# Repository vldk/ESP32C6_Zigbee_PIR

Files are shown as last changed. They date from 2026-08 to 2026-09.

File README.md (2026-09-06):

# ESP32-C6 Zigbee PIR presence sensor (ESP-IDF)

Native ESP-IDF port of `docs/esp32c6_AM312_pullup_v3_2.ino`, with the deep-sleep
cycle replaced by the esp-zigbee sleep feature (automatic light sleep).

- Board: Seeed XIAO ESP32-C6
- Stack: ESP-IDF 6.0.1 + `espressif/esp-zigbee-lib` 1.6.x (Zigbee End Device)
- Build: PlatformIO, `framework = espidf`

---

## Why the sleep mode changed

The Arduino sketch did all its work inside `setup()` and ended every wake in
`esp_deep_sleep_start()`. Deep sleep wipes RAM, so each motion event paid for a
full boot, radio init and parent rejoin before the occupancy report could leave
the device.

Light sleep keeps RAM, the radio state and the network join intact. The Zigbee
stack raises `ESP_ZB_COMMON_SIGNAL_CAN_SLEEP` whenever it is idle;
`esp_zb_sleep_now()` releases its power-management lock, and the IDF tickless
idle takes the SoC down until the next parent poll, GPIO edge or timer alarm.

| | Deep sleep (sketch) | Light sleep (this port) |
|---|---|---|
| Motion report latency | boot + rejoin | milliseconds |
| RAM across sleep | lost | retained |
| Motion vs. button wake | ambiguous, disambiguated by re-reading GPIO7 | distinct interrupts |
| z2m config write | needed an explicit `CONFIG_LISTEN_S` awake window | arrives on the next ordinary parent poll |
| Occupancy hold | busy-wait loop with `delay(50)` | `esp_timer`, asleep in between |

---

## Runtime shape

Every module is a producer; `app_task` in `main.c` is the only consumer, so all
application state lives on one thread and needs no locking.

```
   GPIO1 (PIR) ──┐  level ISR
   GPIO7 (btn) ──┤  + light-sleep wake
                 │
        board_io ├──────────────┐
                 │              │
   esp_timer ────┤ hold         ├──►  s_events queue  ──►  app_task
   alarms        │ supervise    │                            │
                 │ heartbeat    │                            │
                 │ reset-hold   │                            │
                 │              │                            ▼
        zb_sensor├──────────────┘                    set_occupancy()
        (stack task)                                 report_battery()
             ▲                                       settings_set_hold_s()
             └───────────────────────────────────────────────┘
                        esp_zb_lock_acquire()
```

| File | Responsibility |
|---|---|
| `src/app_config.h` | every pin and tunable, single source of truth |
| `src/app_events.h` | the one message type crossing thread boundaries |
| `src/board_io.c` | PIR / button / LED, GPIO light-sleep wake |
| `src/battery.c` | ADC oneshot + curve-fitting calibration -> mV, % |
| `src/settings.c` | NVS store for the occupancy hold setpoint |
| `src/zb_sensor.c` | endpoints, clusters, reports, signal handler, sleep hook |
| `src/main.c` | wiring and the occupancy state machine |

---

## The one subtle part: level-triggered GPIO

The GPIO peripheral is clocked from APB, which stops during light sleep, so an
**edge** that happens while the chip sleeps is lost. Only a **level** survives:
`gpio_wakeup_enable()` wakes the chip while the pin sits at the configured
level, and that level is still there when the ISR finally runs.

So `board_io.c` arms each input for the level it does *not* currently have —
for both the wake source and the interrupt — and flips the watch after every
transition:

```
idle (HIGH) ──arm LOW──►  motion asserted (LOW) ──arm HIGH──►  released ──►  idle
```

The ISR masks the pin (a level interrupt would re-enter forever) and the
application calls `board_io_rearm()` once it has acted. If the line flips back
between the two, the newly armed level already matches and the interrupt fires
immediately — one spurious wake, then self-corrected, never a lost edge.

Two related sdkconfig points:

- `CONFIG_PM_POWER_DOWN_PERIPHERAL_IN_LIGHT_SLEEP=n` — powering the HP
  peripherals down takes the GPIO block with them and makes
  `esp_sleep_enable_gpio_wakeup()` unavailable.
- `CONFIG_PM_SLP_DISABLE_GPIO` is on by default and parks every pad during
  sleep; `gpio_sleep_sel_dis()` is the documented opt-out, applied to the PIR,
  the button and the LED.

---

## The other subtle part: occupancy lives in two places

Keeping RAM across sleep bought fast reports, but it also introduced a problem
deep sleep did not have. The sketch rebooted on every wake and re-reported
occupancy unconditionally each time — including on no-motion heartbeat wakes —
so the coordinator was re-synchronised roughly hourly for free. This port holds
the state in RAM and `set_occupancy()` deduplicates, so a single report that
fails to leave the device desynchronises the coordinator **permanently**: the
device never repeats itself, and z2m has nothing to correct it with.

That is not hypothetical. On 2026-09-04 the sensor reported occupied at
07:20:13Z and z2m did not see a clear until 08:07:53Z — 47 minutes, against a
hold of a few seconds and a 180 s ceiling — while staying joined, reachable and
delivering its heartbeat throughout. Only the next physical motion repaired it,
because `extend_hold()` runs on every PIR edge regardless of the dedupe.

Three mechanisms now reconcile the two copies:

| when | what | covers |
|---|---|---|
| on every report | `publish_occupancy()` records failure in `s_occupancy_unreported` | a report that never left the radio |
| every `OCCUPANCY_SUPERVISE_S` | retry an unreported state; force-clear occupancy older than `OCCUPANCY_MAX_HOLD_S` | a hold timer that never fired |
| every `HEARTBEAT_S` | unconditional re-publish, bypassing the dedupe | everything else |

The force-clear deliberately does **not** live in the hold-timer callback.
`handle_hold_expired()` enforces the same 180 s ceiling, but only when the hold
timer fires — which is exactly the assumption that fails when the state is
stuck. A guard inside the mechanism it guards is not a safety net.

`zb_sensor.c` supports this by returning `ESP_ERR_INVALID_STATE` rather than
`ESP_OK` when a report is skipped because the device is not joined. Reporting
success for something that was never transmitted is what made the failure
invisible in the first place.

---

## Zigbee model

Unchanged from the sketch, so an existing zigbee2mqtt converter keeps working.
All reports are sent **unsolicited**: a sleepy end device never completes the
bind + configureReporting handshake z2m normally does, because it times out
while the device is asleep.

| EP | Cluster | Purpose |
|---|---|---|
| 10 | Occupancy Sensing | `occupancy` |
| 10 | Power Config | `batteryPercentageRemaining` (half-percent units) |
| 11 | Analog Input | battery volts — reportable, unlike the read-only Power-Config `BatteryVoltage` |
| 12 | Analog Output | occupancy hold setpoint in seconds, writable from z2m |

A write to `genAnalogOutput.presentValue` on EP 12 is clamped to
`OCCUPANCY_HOLD_MIN_S..OCCUPANCY_HOLD_MAX_S`, persisted to NVS only when it
actually changed, and echoed back so z2m displays the accepted value. It also
applies to an occupancy period already in progress.

The z2m external converter is `docs/esp32c6_AM312_pullup.mjs`. It accepts both
`AM312_Presence_v2` (the Arduino sketch) and `AM312_Presence_v3` (this port),
since the Zigbee model is identical between them - only the model identifier
string changed.

---

## Hardware

```
  AM312 OUT --[100k]--> Base (2N3904 / BC547 / BC337)
                        Emitter --> GND
                        Collector --> D1 / GPIO1
  D1 / GPIO1 --[1M]--> 3V3          (idle pull-up)

  No motion : AM312 OUT = 0V   -> NPN off -> D1 = HIGH
  Motion    : AM312 OUT = 1.8V -> NPN on  -> D1 = LOW
```

- Battery: LiPo on the BAT pads, `2x1M` divider midpoint -> D0 / GPIO0.
- Factory reset: external momentary switch from GPIO7 (D7) to GND, held 5 s.
  GPIO7 has no on-board button — the physical BOOT button is the GPIO9 strap
  pin and is unusable here.

---

## Build and flash

```bash
pio run                  # build
pio run -t upload        # flash
pio device monitor       # logs (115200, USB-Serial-JTAG)
pio run -t menuconfig    # stack / PM options
```

`sdkconfig.defaults` is only consulted when the per-environment `sdkconfig` is
generated. After editing it, delete `sdkconfig.seeed_xiao_esp32c6` and rebuild.

`board_build.partitions` in `platformio.ini` has to name the same file as
`CONFIG_PARTITION_TABLE_CUSTOM_FILENAME`: PlatformIO generates the partition
table itself and ignores the sdkconfig value. Without it the build silently
falls back to the single-app table and the stack loses `zb_storage`/`zb_fct`.

### Logging

The runtime log level is `CONFIG_LOG_DEFAULT_LEVEL_NONE`, so the firmware is
silent by default: logging over USB-Serial-JTAG keeps that peripheral alive and
dominates the sleep current, and every log call also lengthens the wake it
happens in.

`CONFIG_LOG_MAXIMUM_LEVEL_INFO` is kept, so the strings stay linked (~200 B of
flash) and `esp_log_level_set()` can raise the level at runtime. Note there is
no console or shell on this device to call it from — in practice, getting logs
back means rebuilding with `CONFIG_LOG_DEFAULT_LEVEL_INFO=y`, deleting
`sdkconfig.seeed_xiao_esp32c6` and reflashing. Set
`CONFIG_LOG_MAXIMUM_LEVEL_NONE=y` as well if you want the strings gone
entirely and will never re-enable them.

The two lines worth watching when diagnosing an occupancy desync are
`occupancy -> clear` and `re-sending unreported occupancy state`.

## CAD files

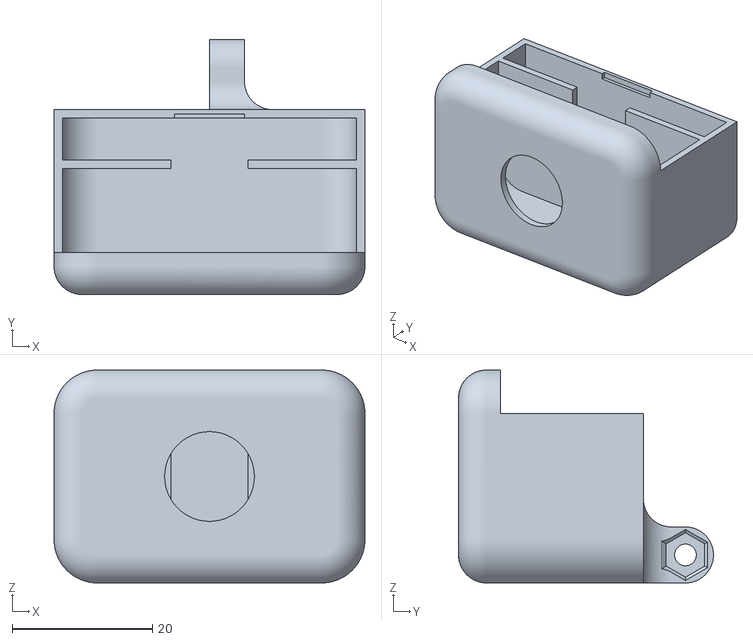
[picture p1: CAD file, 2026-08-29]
3dprint/ESP32C6_PIR_sensor - MainCover.stl
44.4 x 36.4 x 30.4

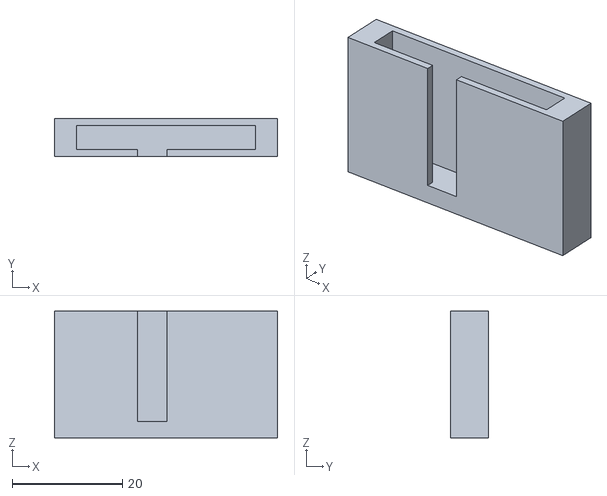
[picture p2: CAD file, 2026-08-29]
3dprint/ESP32C6_PIR_sensor - wallMount.stl
40.4 x 6.80 x 23.0

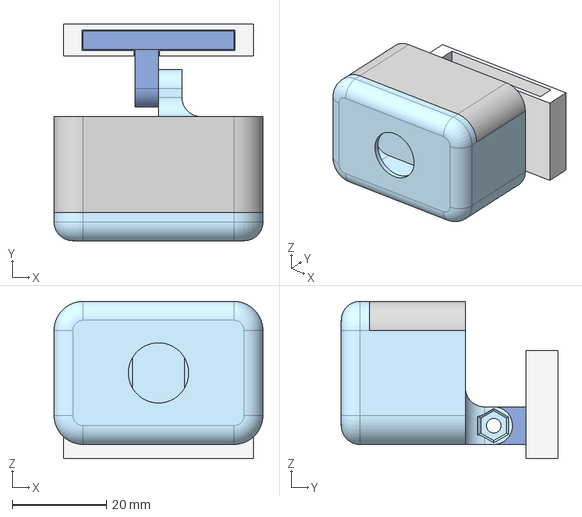
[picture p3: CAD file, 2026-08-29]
3dprint/ESP32C6_PIR_sensor.step
44.4 x 46.0 x 33.4 mm

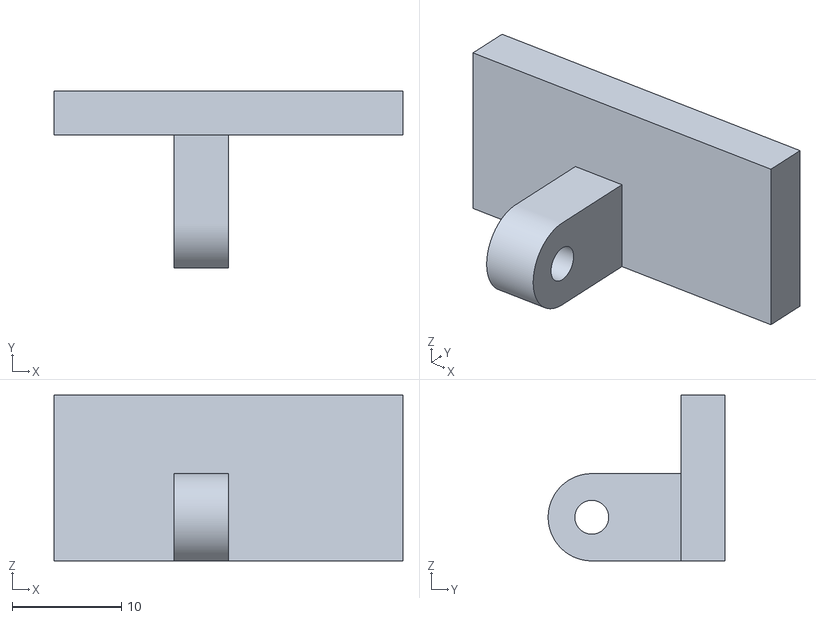
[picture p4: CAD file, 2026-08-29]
3dprint/ESP32C6_PIR_sensor - mountAdapter.stl
32.0 x 16.2 x 15.2

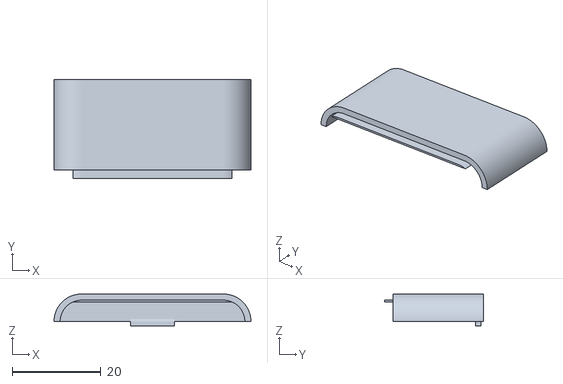
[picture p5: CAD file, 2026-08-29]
3dprint/ESP32C6_PIR_sensor - TopLid.stl
44.4 x 22.4 x 7.20

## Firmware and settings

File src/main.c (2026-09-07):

/*
 * Zigbee battery PIR presence sensor - ESP-IDF port of
 * docs/esp32c6_AM312_pullup_v3_2.ino
 * ---------------------------------------------------------------------------
 * Board : Seeed XIAO ESP32-C6
 * Sensor: AM312 mini PIR -> NPN buffer -> D1/GPIO1
 * Power : LiPo on the BAT pads, sensed through a 2x1M divider on D0/GPIO0
 *
 * What changed against the Arduino sketch
 * ---------------------------------------
 * The sketch ran its whole life inside setup() and ended every wake in
 * esp_deep_sleep_start(), so each motion event cost a full boot, radio init
 * and parent rejoin before the report could leave. This port keeps the device
 * running and joined, and lets the Zigbee stack drop into automatic light
 * sleep between events (see the CAN_SLEEP handler in zb_sensor.c). Practical
 * consequences:
 *
 *   - Motion is reported in milliseconds, not after a boot cycle.
 *   - No more "was this a motion wake or a button wake?" guessing: the GPIO
 *     that woke us also raises a normal interrupt, so the two are distinct.
 *   - The config-receive window is gone. A queued genAnalogOutput write from
 *     z2m is delivered on the next ordinary parent poll, so it no longer has
 *     to be waited for explicitly.
 *
 * Runtime shape - every module is a producer, this file is the only consumer:
 *
 *   board_io (GPIO ISR) --.
 *   esp_timer alarms -----+--> s_events queue --> app_task state machine
 *   zb_sensor (stack) ----'
 */

#include <inttypes.h>

#include "app_config.h"
#include "app_events.h"
#include "battery.h"
#include "board_io.h"
#include "esp_check.h"
#include "esp_log.h"
#include "esp_pm.h"
#include "esp_system.h"
#include "esp_timer.h"
#include "freertos/FreeRTOS.h"
#include "freertos/queue.h"
#include "freertos/task.h"
#include "nvs_flash.h"
#include "sdkconfig.h"
#include "settings.h"
#include "zb_sensor.h"

static const char *TAG = "app";

#define APP_QUEUE_LENGTH    12
#define APP_TASK_STACK_SIZE 4096
#define APP_TASK_PRIORITY   4

static QueueHandle_t     s_events;
static esp_timer_handle_t s_hold_timer;       /* occupancy stay-on          */
static esp_timer_handle_t s_supervise_timer;  /* occupancy state supervisor */
static esp_timer_handle_t s_heartbeat_timer;  /* periodic battery report    */
static esp_timer_handle_t s_reset_timer;      /* button held long enough    */

static bool    s_occupied;
static int64_t s_occupied_since_us;
/* When the hold is currently due to end. The queued APP_EVT_HOLD_EXPIRED is not
 * self-describing, so this is what tells a stale one from a real one - see
 * handle_hold_expired(). */
static int64_t s_hold_deadline_us;
/* Set when an occupancy report did not make it out. The coordinator is the only
 * place this state is visible to anyone, so a dropped report has to be retried
 * rather than logged and forgotten - see handle_supervise(). */
static bool    s_occupancy_unreported;
/* 0 while the device has a network. Otherwise when it lost one, which is what
 * lets handle_supervise() tell a rejoin that is in progress from one that is
 * never going to finish. Armed only after a first successful join, so pairing a
 * factory-new device is never interrupted by the reboot below. */
static int64_t s_link_down_since_us;

/* ------------------------------------------------------------------ timers */

/* esp_timer callbacks run in the timer task, so they only enqueue - all state
 * lives in app_task and needs no locking. */
static void timer_post_event(void *arg)
{
    const app_event_t evt = { .id = (app_event_id_t)(intptr_t)arg };
    if (xQueueSend(s_events, &evt, 0) != pdTRUE) {
        ESP_LOGW(TAG, "application queue full, dropped timer event %d", (int)evt.id);
    }
}

static esp_err_t timer_create(esp_timer_handle_t *out, app_event_id_t event_id, const char *name)
{
    const esp_timer_create_args_t args = {
        .callback = timer_post_event,
        .arg      = (void *)(intptr_t)event_id,
        .name     = name,
        /* ESP_TIMER_TASK, not ISR: the callback touches a FreeRTOS queue. */
        .dispatch_method = ESP_TIMER_TASK,
    };
    return esp_timer_create(&args, out);
}

static void timer_restart_once(esp_timer_handle_t timer, uint64_t timeout_us)
{
    /* esp_timer_stop() returns ESP_ERR_INVALID_STATE when the timer is not
     * armed, which is a normal case here, not an error. */
    esp_timer_stop(timer);

    const esp_err_t err = esp_timer_start_once(timer, timeout_us);
    if (err != ESP_OK) {
        ESP_LOGE(TAG, "cannot arm timer: %s", esp_err_to_name(err));
    }
}

/* -------------------------------------------------------------- occupancy */

/* The single point every occupancy report goes through, so that a failure is
 * remembered instead of merely logged. Local state is committed first on
 * purpose: the LED and the hold logic must reflect the sensor even when the
 * radio is unavailable. It is the coordinator that then has to catch up. */
static void publish_occupancy(void)
{
    const esp_err_t err = zb_sensor_report_occupancy(s_occupied);
    s_occupancy_unreported = (err != ESP_OK);

    if (err != ESP_OK) {
        ESP_LOGE(TAG, "occupancy report failed (%s), retrying within %u s",
                 esp_err_to_name(err), (unsigned)OCCUPANCY_SUPERVISE_S);
    }
}

static void set_occupancy(bool occupied)
{
    if (s_occupied == occupied) {
        /* Deduplicated, but never silently: if the last attempt for this very
         * value failed, the coordinator still disagrees with us and this is a
         * free chance to fix that. */
        if (s_occupancy_unreported) {
            publish_occupancy();
        }
        return;
    }
    s_occupied = occupied;
    if (occupied) {
        s_occupied_since_us = esp_timer_get_time();
    }

    ESP_LOGI(TAG, "occupancy -> %s", occupied ? "occupied" : "clear");

    publish_occupancy();
}

static void extend_hold(void)
{
    const uint64_t hold_us = (uint64_t)settings_get_hold_s() * 1000000ULL;

    s_hold_deadline_us = esp_timer_get_time() + (int64_t)hold_us;
    timer_restart_once(s_hold_timer, hold_us);
}

static void handle_pir_changed(bool motion)
{
    ESP_ERROR_CHECK_WITHOUT_ABORT(board_io_rearm(BOARD_INPUT_PIR));

    /* The LED tracks the PIR line, not the occupancy it produces: it answers
     * "is the sensor seeing something right now?", which is the question worth
     * asking when aiming the lens or checking the AM312 still works. Occupancy
     * deliberately outlives the pulse by hold_s - the LED deliberately does
     * not, so the two are read independently. board_io_led_blink() is
     * unaffected and still owns the start-up and factory-reset signalling. */
    board_io_led_set(motion);

    if (motion) {
        set_occupancy(true);
    }
    /* Restarted on the trailing edge too, so the hold is measured from the end
     * of the AM312 pulse rather than from its start. */
    extend_hold();
}

static bool occupancy_outlived_max_hold(void)
{
    return (esp_timer_get_time() - s_occupied_since_us) >=
           (int64_t)OCCUPANCY_MAX_HOLD_S * 1000000LL;
}

static void handle_hold_expired(void)
{
    if (!s_occupied) {
        return;
    }

    /* The event carries no timestamp, so a HOLD_EXPIRED that was already sitting
     * in the queue when a PIR edge ran extend_hold() would otherwise clear an
     * occupancy that had just been prolonged - the classic lost-extension race.
     * The deadline moved, so this event is stale: drop it and let the re-armed
     * timer deliver the real one. esp_timer never fires early (light sleep only
     * ever makes it late), so a legitimate expiry always passes this test. */
    if (esp_timer_get_time() < s_hold_deadline_us) {
        return;
    }

    if (board_io_motion_active()) {
        if (!occupancy_outlived_max_hold()) {
            extend_hold();
            return;
        }
        /* The buffered line has been asserted for longer than any real person
         * triggers it - most likely the transistor or the pull-up has failed.
         * Clear anyway so the sensor does not latch "occupied" forever. */
        ESP_LOGW(TAG, "PIR line asserted for over %u s, forcing clear (is D1 stuck LOW?)",
                 (unsigned)OCCUPANCY_MAX_HOLD_S);
    }

    set_occupancy(false);
}

/*
 * Runs on a fixed cadence and reconciles the two things the hold timer cannot
 * fix, because in both of them the hold timer is the part that failed.
 */
static void handle_supervise(void)
{
    /* (1) Occupancy that outlived every legitimate hold. handle_hold_expired()
     * enforces the same ceiling, but only if the hold timer actually fires -
     * which is precisely what cannot be assumed when the state is stuck. A
     * guard living inside the mechanism it guards is not a safety net; this
     * separate alarm is. */
    if (s_occupied && occupancy_outlived_max_hold()) {
        ESP_LOGW(TAG, "occupied for over %u s with no hold expiry, forcing clear",
                 (unsigned)OCCUPANCY_MAX_HOLD_S);
        esp_timer_stop(s_hold_timer);
        set_occupancy(false);
        return;   /* set_occupancy() has just reported; nothing left to retry */
    }

    /* (2) A state the coordinator was never successfully told about. */
    if (s_occupancy_unreported) {
        ESP_LOGW(TAG, "re-sending unreported occupancy state (%s)",
                 s_occupied ? "occupied" : "clear");
        publish_occupancy();
    }

    /* (3) A network that has been gone long enough that the stack is plainly not
     * getting it back. Everything above is a no-op while there is no parent to
     * report to, so this is the rung that actually restores service. Last,
     * because a reboot discards the local state the first two rungs just fixed.
     * The LED needs no attention: board_io_init() drives it low on the way back
     * up, and app_task() re-lights it if the line is still asserted. */
    if (s_link_down_since_us != 0 &&
        (esp_timer_get_time() - s_link_down_since_us) >=
            (int64_t)ZB_RELINK_REBOOT_S * 1000000LL) {
        ESP_LOGE(TAG, "no network for over %u s, rebooting to re-commission",
                 (unsigned)ZB_RELINK_REBOOT_S);
        esp_restart();
    }
}

/* The stack lost the network. zb_sensor.c has already kicked off fresh steering;
 * all that is needed here is to start the clock that bounds how long it may
 * keep failing. */
static void handle_zb_left(void)
{
    if (s_link_down_since_us == 0) {
        s_link_down_since_us = esp_timer_get_time();
    }
}

/* ----------------------------------------------------------------- button */

static void handle_button_changed(bool pressed)
{
    ESP_ERROR_CHECK_WITHOUT_ABORT(board_io_rearm(BOARD_INPUT_BUTTON));

    if (pressed) {
        timer_restart_once(s_reset_timer, (uint64_t)RESET_HOLD_S * 1000000ULL);
    } else {
        esp_timer_stop(s_reset_timer);
    }
}

static void handle_reset_hold_elapsed(void)
{
    if (!board_io_button_pressed()) {
        return;   /* released during the last tick; ignore */
    }

    ESP_LOGW(TAG, "reset button held for %u s", (unsigned)RESET_HOLD_S);
    board_io_led_blink(5, 600);   /* ~3 s of blinking so the user sees it registered */
    zb_sensor_factory_reset();    /* erases the datasets and reboots; never returns */
}

/* -------------------------------------------------------------- reporting */

static void report_battery(void)
{
    uint16_t millivolts = 0;
    uint8_t  percent    = 0;

    const esp_err_t err = battery_read(&millivolts, &percent);
    if (err != ESP_OK) {
        ESP_LOGE(TAG, "battery read failed: %s", esp_err_to_name(err));
        return;
    }

    ESP_LOGI(TAG, "battery: %u mV -> %u%% (%.3f V), hold %" PRIu32 " s",
             millivolts, percent, millivolts / 1000.0f, settings_get_hold_s());

    const esp_err_t report_err = zb_sensor_report_battery(millivolts, percent);
    if (report_err != ESP_OK) {
        ESP_LOGE(TAG, "battery report failed: %s", esp_err_to_name(report_err));
    }
}

static void handle_joined(void)
{
    s_link_down_since_us = 0;

    report_battery();

    const esp_err_t err = zb_sensor_report_hold_setpoint(settings_get_hold_s());
    if (err != ESP_OK) {
        ESP_LOGE(TAG, "hold setpoint report failed: %s", esp_err_to_name(err));
    }

    /* Publish the current state so the coordinator is not left guessing after
     * a rejoin, then start the keepalive/battery cadence. */
    publish_occupancy();

    esp_timer_stop(s_heartbeat_timer);
    const esp_err_t timer_err =
        esp_timer_start_periodic(s_heartbeat_timer, (uint64_t)HEARTBEAT_S * 1000000ULL);
    if (timer_err != ESP_OK) {
        ESP_LOGE(TAG, "cannot start the heartbeat timer: %s", esp_err_to_name(timer_err));
    }
}

/* z2m wrote genAnalogOutput.presentValue on the config endpoint. Clamp it,
 * persist it and echo back what was actually accepted. */
static void handle_hold_setpoint(float requested)
{
    if (requested < 0.0f) {
        requested = 0.0f;
    }

    uint32_t applied = 0;
    const esp_err_t err = settings_set_hold_s((uint32_t)(requested + 0.5f), &applied);
    if (err != ESP_OK) {
        ESP_LOGE(TAG, "cannot store the hold setpoint: %s", esp_err_to_name(err));
    }

    const esp_err_t report_err = zb_sensor_report_hold_setpoint(applied);
    if (report_err != ESP_OK) {
        ESP_LOGE(TAG, "hold setpoint echo failed: %s", esp_err_to_name(report_err));
    }

    /* A shortened hold should take effect on the current occupancy too. */
    if (s_occupied) {
        extend_hold();
    }
}

/* ------------------------------------------------------------- app task */

static void app_task(void *arg)
{
    /* If the PIR line is already asserted at boot, treat it as motion: the
     * original sketch made the same call for a GPIO deep-sleep wake. */
    if (board_io_motion_active()) {
        ESP_LOGI(TAG, "PIR asserted at start-up");
        /* Seeded here rather than by set_occupancy(): the two blinks in
         * app_main() leave the LED off, and nothing else lights it until the
         * next PIR edge - which a line that is already asserted will not give. */
        board_io_led_set(true);
        set_occupancy(true);
        extend_hold();
    }

    app_event_t evt;
    while (xQueueReceive(s_events, &evt, portMAX_DELAY) == pdTRUE) {
        switch (evt.id) {
        case APP_EVT_PIR_CHANGED:
            handle_pir_changed(evt.level_asserted);
            break;
        case APP_EVT_BUTTON_CHANGED:
            handle_button_changed(evt.level_asserted);
            break;
        case APP_EVT_HOLD_EXPIRED:
            handle_hold_expired();
            break;
        case APP_EVT_RESET_HOLD_ELAPSED:
            handle_reset_hold_elapsed();
            break;
        case APP_EVT_SUPERVISE:
            handle_supervise();
            break;
        case APP_EVT_HEARTBEAT:
            report_battery();
            /* Unconditional occupancy re-publish, bypassing the set_occupancy()
             * dedupe. The deep-sleep sketch this replaced got this for free -
             * it re-reported occupancy on every single wake - and losing it is
             * what let a desync survive indefinitely instead of at most one
             * heartbeat. This is the backstop for whatever the supervision tick
             * above does not anticipate. */
            publish_occupancy();
            break;
        case APP_EVT_ZB_JOINED:
            handle_joined();
            break;
        case APP_EVT_ZB_LEFT:
            handle_zb_left();
            break;
        case APP_EVT_ZB_HOLD_SETPOINT:
            handle_hold_setpoint(evt.setpoint);
            break;
        default:
            ESP_LOGW(TAG, "unknown event %d", (int)evt.id);
            break;
        }
    }

    vTaskDelete(NULL);
}

/* ------------------------------------------------------------------- init */

static esp_err_t power_management_init(void)
{
#if CONFIG_PM_ENABLE
    /* esp_zb_sleep_now() only releases the stack power-management lock. It is
     * this configuration - with light_sleep_enable - that turns the resulting
     * idle into an actual light sleep. Without it the CPU would simply spin. */
    const esp_pm_config_t pm_config = {
        .max_freq_mhz       = CONFIG_ESP_DEFAULT_CPU_FREQ_MHZ,
        .min_freq_mhz       = CONFIG_XTAL_FREQ,
        .light_sleep_enable = true,
    };
    ESP_RETURN_ON_ERROR(esp_pm_configure(&pm_config), TAG, "cannot configure power management");
    ESP_LOGI(TAG, "automatic light sleep enabled (%d..%d MHz)",
             CONFIG_XTAL_FREQ, CONFIG_ESP_DEFAULT_CPU_FREQ_MHZ);
    return ESP_OK;
#else
#warning "CONFIG_PM_ENABLE is off: the device will stay awake and drain the battery"
    ESP_LOGW(TAG, "power management disabled at build time - no light sleep");
    return ESP_OK;
#endif
}

static esp_err_t nvs_init(void)
{
    esp_err_t err = nvs_flash_init();
    if (err == ESP_ERR_NVS_NO_FREE_PAGES || err == ESP_ERR_NVS_NEW_VERSION_FOUND) {
        ESP_LOGW(TAG, "NVS unusable (%s), erasing it", esp_err_to_name(err));
        ESP_RETURN_ON_ERROR(nvs_flash_erase(), TAG, "cannot erase NVS");
        err = nvs_flash_init();
    }
    return err;
}

void app_main(void)
{
    ESP_ERROR_CHECK(nvs_init());
    ESP_ERROR_CHECK(settings_init());

    s_events = xQueueCreate(APP_QUEUE_LENGTH, sizeof(app_event_t));
    ESP_ERROR_CHECK(s_events != NULL ? ESP_OK : ESP_ERR_NO_MEM);

    ESP_ERROR_CHECK(timer_create(&s_hold_timer, APP_EVT_HOLD_EXPIRED, "hold"));
    ESP_ERROR_CHECK(timer_create(&s_supervise_timer, APP_EVT_SUPERVISE, "supervise"));
    ESP_ERROR_CHECK(timer_create(&s_heartbeat_timer, APP_EVT_HEARTBEAT, "heartbeat"));
    ESP_ERROR_CHECK(timer_create(&s_reset_timer, APP_EVT_RESET_HOLD_ELAPSED, "reset"));

    /* Started here rather than on join: an occupancy report that fails because
     * we are not on a network yet is exactly one of the cases it has to retry. */
    ESP_ERROR_CHECK(esp_timer_start_periodic(s_supervise_timer,
                                             (uint64_t)OCCUPANCY_SUPERVISE_S * 1000000ULL));

    ESP_ERROR_CHECK(board_io_init(s_events));
    ESP_ERROR_CHECK(battery_init());
    ESP_ERROR_CHECK(power_management_init());

    /* Same two short flashes the sketch used to signal "firmware is alive". */
    board_io_led_blink(2, 200);

    const zb_sensor_config_t zb_config = {
        .event_sink     = s_events,
        .initial_hold_s = settings_get_hold_s(),
    };
    ESP_ERROR_CHECK(zb_sensor_start(&zb_config));

    ESP_ERROR_CHECK(xTaskCreate(app_task, "app", APP_TASK_STACK_SIZE, NULL,
                                APP_TASK_PRIORITY, NULL) == pdPASS
                        ? ESP_OK
                        : ESP_ERR_NO_MEM);

    ESP_LOGI(TAG, "started: hold %" PRIu32 " s, supervise %u s, heartbeat %u s, model %s",
             settings_get_hold_s(), (unsigned)OCCUPANCY_SUPERVISE_S, (unsigned)HEARTBEAT_S,
             ZB_MODEL_IDENTIFIER);
}

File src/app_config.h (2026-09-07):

/*
 * Single source of truth for every pin and tunable in the sensor.
 * Nothing else in the project hard-codes a GPIO number or a timeout.
 */
#pragma once

#include "driver/gpio.h"

/* ---------------- Pins ---------------------------------------------------
 * AM312 OUT --[100k]--> Base (2N3904)
 *                       Emitter --> GND
 *                       Collector --> D1 / GPIO1
 * D1 / GPIO1 --[1M]--> 3V3
 *   No motion : AM312 OUT = 0V   -> NPN off -> D1 = HIGH
 *   Motion    : AM312 OUT = 1.8V -> NPN on  -> D1 = LOW
 * The NPN buffer inverts the signal, hence the active-LOW levels below.
 */
#define PIN_PIR                 GPIO_NUM_1      /* D1, buffered PIR signal   */
#define PIN_BATTERY             GPIO_NUM_0      /* D0, 2x1M divider midpoint */
#define PIN_BUTTON              GPIO_NUM_7      /* D7, external switch to GND */
#define PIN_LED                 GPIO_NUM_15     /* on-board user LED         */

#define PIR_ACTIVE_LEVEL        0               /* LOW = motion              */
#define BUTTON_ACTIVE_LEVEL     0               /* LOW = pressed             */
#define LED_ACTIVE_LEVEL        0               /* LOW = lit                 */

/* ---------------- Behaviour --------------------------------------------- */
#define OCCUPANCY_HOLD_DEFAULT_S    30U         /* factory default stay-occupied time */
#define OCCUPANCY_HOLD_MIN_S        1U          /* clamp: report even brief motion    */
#define OCCUPANCY_HOLD_MAX_S        3600U       /* clamp: one hour                    */

/* Safety net for a buffered PIR line that is stuck asserted (dead transistor,
 * shorted collector). Without it the hold timer would re-arm forever and the
 * sensor would stay "occupied" until the battery ran out. */
#define OCCUPANCY_MAX_HOLD_S        180U

/* Supervision tick, independent of the hold timer.
 *
 * Occupancy lives in exactly two places - here and in the coordinator - and
 * nothing reconciles them: set_occupancy() dedupes, so a state that is wrong on
 * one side stays wrong until the next real transition. A 47-minute false
 * "occupied" was traced to that (2026-09-04; the device stayed joined and
 * reachable throughout, so no clear was ever generated or delivered).
 *
 * This tick is the reconciliation, and it covers what the hold timer cannot:
 * it re-sends a report that failed, and it force-clears an occupancy that has
 * outlived OCCUPANCY_MAX_HOLD_S even when the hold timer never fired at all.
 * The stack already wakes the SoC every ZB_ED_KEEPALIVE_MS to poll the parent,
 * so a 30 s alarm costs no measurable battery, and it only transmits when
 * something is actually wrong. */
#define OCCUPANCY_SUPERVISE_S       30U

#define HEARTBEAT_S                 (60U * 60U) /* battery + keepalive report period */

/* How long the device tolerates having no network before rebooting itself.
 *
 * Network steering retries on its own, but a stack that has wedged its radio
 * state retries forever without ever getting back on. A reboot re-commissions
 * from the NVS dataset in a few seconds, so the trade is a handful of seconds
 * of downtime against the alternative that actually happened: a device sitting
 * silent for 17 hours (2026-09-07) with nothing able to recover it. Comfortably
 * longer than a coordinator restart so a routine bounce does not trip it. */
#define ZB_RELINK_REBOOT_S          (15U * 60U)
#define RESET_HOLD_S                5U          /* button hold to factory reset      */

/* ---------------- Battery divider --------------------------------------- */
#define BATTERY_DIVIDER_RATIO   2.0f            /* 2x1M -> divide by 2 */
#define BATTERY_MIN_MV          3000.0f         /* 0%   (~empty LiPo)  */
#define BATTERY_MAX_MV          4200.0f         /* 100% (full LiPo)    */
#define BATTERY_SAMPLES         8               /* averaged per reading */

/* ---------------- Zigbee ------------------------------------------------- */
#define ZB_ENDPOINT_OCCUPANCY   10              /* occupancy + battery percentage    */
#define ZB_ENDPOINT_BATTERY     11              /* battery volts as Analog Input     */
#define ZB_ENDPOINT_CONFIG      12              /* hold setpoint as Analog Output    */

#define ZB_MANUFACTURER_NAME    "DIY"
#define ZB_MODEL_IDENTIFIER     "AM312_Presence_v3"

/* How long the parent buffers data for us, and how often we poll it. Shorter
 * = z2m writes land sooner, longer = less radio time and more battery life. */
#define ZB_ED_KEEPALIVE_MS      3000U

/* Do not bother light sleeping for anything shorter than this - the wake-up
 * itself would cost more energy than staying awake. */
#define ZB_SLEEP_THRESHOLD_MS   20U

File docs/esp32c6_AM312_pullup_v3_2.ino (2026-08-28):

/*
 * Zigbee battery PIR presence sensor
 * ----------------------------------
 * Board : Seeed XIAO ESP32-C6
 * Sensor: AM312 mini PIR  ->  NPN buffer  ->  D1/GPIO1 (LP/RTC pin, wakes deep sleep)
 * Power : LiPo on BAT pads, battery sense via 2x1MegOhm divider -> D0/GPIO0
 *
 * ---- Battery reporting ----
 * Percentage: reported via the Power-Config cluster (occupancy endpoint 10).
 * Voltage   : the standard Power-Config BatteryVoltage attribute (0x0020) is
 *   READ-ONLY / NON-REPORTABLE in this library (z2m configReport returns
 *   UNREPORTABLE_ATTRIBUTE), so we CANNOT push it. Instead we report the battery
 *   voltage (in volts) through an Analog Input cluster on a 2nd endpoint (11),
 *   which IS reportable. z2m maps genAnalogInput.presentValue -> "voltage".
 *   Both are sent as UNSOLICITED reports each wake, so no bind / configureReporting
 *   is needed (those time out on a sleepy end device anyway).
 *
 * ---- Configurable occupancy hold (NEW) ----
 * OCCUPANCY_HOLD_S is now the DEFAULT only. The live value is stored in NVS and
 * is settable from z2m via an Analog Output cluster on a 3rd endpoint (12).
 * z2m writes genAnalogOutput.presentValue; the device receives it during its
 * awake window (it polls its parent for the queued write), clamps + saves it to
 * NVS, and echoes it back so z2m confirms the accepted value.
 *   NOTE: because this is a sleepy end device, a change you make in z2m is queued
 *   and only lands the NEXT time the sensor wakes (motion, or the heartbeat), and
 *   only takes effect from the wake AFTER that. Allow up to one HEARTBEAT_S.
 *
 * ---- Recovery note ----
 * If Zigbee.begin() fails we DEEP-SLEEP and retry instead of ESP.restart()
 * (a software reset does not reliably re-init the C6's 802.15.4 radio).
 *
 * ---- Factory reset / re-pair (GPIO7 button, hold 5s) ----
 * Wire an external momentary switch from GPIO7 (D7) to GND. Hold it to GND for
 * RESET_HOLD_S seconds to leave the Zigbee network and reboot into pairing mode.
 * This works in EVERY state:
 *   - Sleeping : GPIO7 is a deep-sleep wake source, so pressing the button wakes
 *                the device; keep holding 5s and it factory-resets.
 *   - Awake but not joined (stuck connecting): the connect loop polls the button.
 *   - Cold boot / interview window: also polled.
 * GPIO7 is an LP/RTC pin (GPIO0-7), required for deep-sleep GPIO wakeup. Its
 * internal pull-up is auto-enabled during deep sleep (idle = HIGH), so no external
 * pull-up is needed; add a 1M to 3V3 if you want extra noise margin.
 * NOTE: GPIO7 has no ONBOARD button (the physical BOOT button is the GPIO9 strap
 * pin, unusable here). Wire an external momentary switch to GND on GPIO7 to use it.
 *
 * ---- Why the buffer transistor ----
 *   AM312 OUT --[100k]--> Base (2N3904 / BC547 / BC337)
 *                         Emitter --> GND
 *                         Collector --> D1 / GPIO1
 *   D1 / GPIO1 --[1M]--> 3V3           (pull-up: holds the line HIGH when idle)
 *   No motion : AM312 OUT = 0V   -> NPN off -> D1 = HIGH
 *   Motion    : AM312 OUT = 1.8V -> NPN on  -> D1 = LOW   <- wake on this
 *
 * ---- Arduino IDE settings (Tools menu) ----
 *   Board            : XIAO_ESP32C6   (ESP32 board package 3.x)
 *   Zigbee Mode      : Zigbee ED (end device)
 *   Partition Scheme : Zigbee 4MB with spiffs
 *   Erase All Flash  : DISABLED once joined (Enabled only to wipe & re-pair)
 */

#ifndef ZIGBEE_MODE_ED
#error "Select Tools > Zigbee Mode > Zigbee ED (end device) before compiling."
#endif

#include "Zigbee.h"
#include "esp_sleep.h"
#include <Preferences.h>   // NVS-backed key/value store (survives power loss)

// ---------------- Pins ----------------
#define PIR_PIN        1     // D1 / GPIO1  (buffered PIR signal) - LP/RTC pin (GPIO0-7)
#define BATTERY_PIN    0     // D0 / GPIO0  (ADC on the divider mid-point)
#define BOOT_BUTTON    7     // GPIO7 (D7) -> external button to GND. Hold RESET_HOLD_S to
                             // factory-reset + re-pair. LP/RTC pin so it can wake deep sleep.

#define ZB_JOIN_RETRY_S  30  // if the stack won't start/join, sleep this long then retry
#define RESET_HOLD_S     5   // hold the GPIO7 button to GND continuously this long -> factory reset

// Built-in user LED on the XIAO ESP32-C6 is GPIO15 and is ACTIVE-LOW (LOW = lit).
#define LED_PIN          15
#define LED_ON           LOW
#define LED_OFF          HIGH

// The NPN buffer inverts the signal: motion pulls the pin LOW, idle is HIGH.
#define MOTION_LEVEL   LOW    // digitalRead(PIR_PIN) == MOTION_LEVEL  means "motion"

// ---------------- Behaviour ----------------
#define OCCUPANCY_HOLD_DEFAULT_S  30          // DEFAULT stay-occupied time (now configurable via z2m)
#define OCCUPANCY_HOLD_MIN_S      1           // clamp: refuse anything shorter (1s = report even brief motion)
#define OCCUPANCY_HOLD_MAX_S      3600        // clamp: refuse anything longer (1 h)
#define HEARTBEAT_S          (60 * 60)   // wake at least this often (battery + keepalive)
#define MAX_AWAKE_S          180         // safety: force clear+sleep after this even if motion stays asserted
#define CONFIG_LISTEN_S      1           // AFTER occupancy is reported, stay awake this long so the stack can
                                         // poll the parent for a queued genAnalogOutput (config) write from z2m.
                                         // It runs post-occupancy, so it never delays a motion report -- raise
                                         // it for more reliable config reception on heartbeat wakes if needed.

// ---------------- Battery divider ----------------
#define DIV_RATIO      2.0f    // 2x1MegOhm -> divide by 2
#define VBAT_MIN_MV    3000.0f // 0%   (~empty LiPo)
#define VBAT_MAX_MV    4200.0f // 100% (full LiPo)

// ---------------- Zigbee endpoints ----------------
#define OCCUPANCY_ENDPOINT   10
#define ANALOG_ENDPOINT      11
#define CONFIG_ENDPOINT      12
ZigbeeOccupancySensor zbOccupancy = ZigbeeOccupancySensor(OCCUPANCY_ENDPOINT);
ZigbeeAnalog          zbBattV     = ZigbeeAnalog(ANALOG_ENDPOINT);   // battery voltage (V)
ZigbeeAnalog          zbConfig    = ZigbeeAnalog(CONFIG_ENDPOINT);   // occupancy-hold setpoint (s)

// ---------------- Configurable state ----------------
Preferences prefs;
uint32_t occupancyHoldS = OCCUPANCY_HOLD_DEFAULT_S;   // live value, loaded from NVS in setup()

// Set from the Zigbee-stack callback context; consumed in setup(). Kept tiny/volatile
// so we do NOT do NVS writes or ZCL reports inside the stack callback itself.
volatile bool  g_holdPending    = false;
volatile float g_holdPendingVal = 0.0f;

// -------------------------------------------------
inline bool motionPresent() {
  return digitalRead(PIR_PIN) == MOTION_LEVEL;
}
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

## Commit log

2026-08-29 Added 3d printable models for cover
    [ESP32C6_PIR_sensor - MainCover.stl, ESP32C6_PIR_sensor - TopLid.stl, ESP32C6_PIR_sensor - mountAdapter.stl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]
2026-09-04 :bugfix: fix case with stuck "occupidd" state
    [app_config.h, main.c]
2026-09-06 :bugfix: drop stale hold-expiry events, rename occupancy_timeout expose, silence logs by default
    [main.c]
2026-09-07 :bugfix: clear s_joined on parent link failure, reboot after prolonged link down, restore task WDT, coredump and WARN logs
    Claude-Session: https://claude.ai/code/session_01RrBPxTzeNji2WJEDuX7Jvq
    [partitions.csv]
2026-09-07 :feature: drive the LED from the PIR line instead of the occupancy hold, so it goes out with the pulse rather than after hold_s
    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
